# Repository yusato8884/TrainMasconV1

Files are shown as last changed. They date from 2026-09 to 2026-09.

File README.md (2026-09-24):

# TrainMasconV1

自作ゲーム「[Tozai Sim Pro](https://tozai-sim.base44.app/)」用の、USBキーボードとして動作する自作マスコン（主幹制御器）コントローラーです。
可変抵抗（2連ボリューム）のレバー位置を読み取り、ノッチ（P4〜N〜B7〜EB）に応じたキー入力をPCへ送ります。
現在のノッチは0.96インチOLEDに大きく表示されます。

- マイコン: AE-RP2040（MicroPython）
- 表示: SSD1306 OLED 128x64（I2C）
- 入力: 可変抵抗 1個（ADC）＋ ボタン 3個
- 接続: USB HID キーボード

ドキュメント: <https://y-trm1doc.base44.app/>

## ディレクトリ構成

```
Firmware/
  LICENSE                               ソフトウェアのライセンス（MIT）
  main.py                               本体ファームウェア（ノッチ→キー入力、OLED表示、USB HID）
  vrcalib.py                            可変抵抗の電圧測定ツール（ノッチ境界の電圧調整用）
Hardware/
  Enclosure/                            3Dプリント用ケース
    TRM1-Case-Top.stl                   ケース上部
    TRM1-Case-Bottom.stl                ケース下部
    TRM1-Case-Handle.stl                ハンドル
    TRM1-Case-Handle-Stopper.stl        ハンドルのストッパー
  PCB/                                  基板データ
    ProPrj_Mascon_2026-09-23.epro2      EasyEDA Pro の原本
    kicad_output/                       KiCad 8 変換版
      Mascon.kicad_pro                  KiCad プロジェクトファイル
      Mascon.kicad_sch                  回路図
      Mascon.kicad_pcb                  基板
      Mascon.kicad_sym                  シンボルライブラリ
      Mascon.kicad_footprints.pretty/   フットプリントライブラリ（.kicad_mod 8点）
      fp-lib-table                      フットプリントライブラリ設定
      sym-lib-table                     シンボルライブラリ設定
      CONVERSION_NOTES.md               変換時の注意事項
  LICENSE                               ハードウェアのライセンス（CERN-OHL-P v2）
README.md                               このファイル
```

## 配線

| 部品 | ピン |
|---|---|
| OLED SDA / SCL | GP20 / GP19（SoftI2C, アドレス 0x3C） |
| ボタン1 / 2 / 3 | GP23 / GP24 / GP25（GND側に接続） |
| 可変抵抗（中点） | GP26 (ADC0)、両端は 3V3 と GND |

## セットアップ

1. AE-RP2040 に MicroPython を書き込みます。
2. 必要なライブラリを導入します。
   ```
   mpremote mip install ssd1306
   mpremote mip install usb-device-keyboard
   ```
3. `Firmware/main.py` を `main.py` として本体に転送します。
4. USBで接続すると、キーボードとして認識されます。

## ノッチの調整

1. `Firmware/vrcalib.py` を実行し、レバーを各ノッチに合わせたときの電圧を読み取ります。
2. `main.py` の `LAYERS` の電圧しきい値（下限V, 上限V）を書き換えます。

既定のキー割り当ては次のとおりです（電圧の低い側から）。

| ノッチ | P4 | P3 | P2 | P1 | N | B1〜B6 | B7 | EB |
|---|---|---|---|---|---|---|---|---|
| キー | 1 | 2 | 3 | 4 | → | 5, 6, 7, 8, 9, 0 | - | Space |

ボタン1を押しながら起動すると安全モード（HID初期化とメインループを行わない）になり、ファイルを編集できます。

## ハードウェア

- `Hardware/PCB/ProPrj_Mascon_2026-09-23.epro2` が基板の原本です。
- `Hardware/PCB/kicad_output/` は KiCad 8 向けの変換結果です（開く場合は `Mascon.kicad_pro` を指定します）。KiCad での動作確認は未実施のため、開く際は [CONVERSION_NOTES.md](Hardware/PCB/kicad_output/CONVERSION_NOTES.md) を確認してください。
- ケースのSTL（`Hardware/Enclosure/` 内の `TRM1-Case-*.stl` 4点）についての注意:
  - サポート材は含まれていません。造形方向やプリンターに応じて、必要ならスライサー側で追加してください。
  - 薄肉部分やクリアランス（はめ合いの隙間）は十分に考慮されていません。
  - そのため、3Dプリントサービスに発注するか、自分で造形する場合は精度の非常に高いプリンター（光造形など）が必要です。一般的なFDMプリンターでは、そのままでは組み立てられない可能性があります。

## ライセンス

ライセンスは、対象ごとにそれぞれのフォルダ内の `LICENSE` に記載されています。

| 対象 | ライセンス | ファイル |
|---|---|---|
| ハードウェア（`Hardware/` 配下: 基板、回路図、ケース） | [CERN-OHL-P v2](Hardware/LICENSE) | `Hardware/LICENSE` |
| ソフトウェア（`Firmware/` 配下） | [MIT](Firmware/LICENSE) | `Firmware/LICENSE` |

SPDX: `CERN-OHL-P-2.0`（ハードウェア）/ `MIT`（ソフトウェア）

[SCANOSS](https://www.scanoss.com/) によるスキャンでは、全ファイルで既存OSSとの一致は検出されませんでした（2026-09-24時点）。

---

# TrainMasconV1

A custom mascon (master controller) controller for my original game "[Tozai Sim Pro](https://tozai-sim.base44.app/)", which operates as a USB keyboard.
It reads the lever position of a variable resistor (dual-gang potentiometer) and sends key inputs to the PC according to the notch (P4〜N〜B7〜EB).
The current notch is displayed prominently on a 0.96-inch OLED.

- Microcontroller: AE-RP2040 (MicroPython)
- Display: SSD1306 OLED 128x64 (I2C)
- Input: 1 variable resistor (ADC) + 3 buttons
- Connection: USB HID keyboard

Documentation: <https://y-trm1doc.base44.app/>

## Directory Structure

```
Firmware/
  LICENSE                               Software license (MIT)
  main.py                               Main firmware (notch→key input, OLED display, USB HID)
  vrcalib.py                            Variable resistor voltage measurement tool (for adjusting notch boundary voltages)
Hardware/
  Enclosure/                            3D-printable case
    TRM1-Case-Top.stl                   Case top
    TRM1-Case-Bottom.stl                Case bottom
    TRM1-Case-Handle.stl                Handle
    TRM1-Case-Handle-Stopper.stl        Handle stopper
  PCB/                                  PCB data
    ProPrj_Mascon_2026-09-23.epro2      EasyEDA Pro original
    kicad_output/                       KiCad 8 converted version
      Mascon.kicad_pro                  KiCad project file
      Mascon.kicad_sch                  Schematic
      Mascon.kicad_pcb                  PCB layout
      Mascon.kicad_sym                  Symbol library
      Mascon.kicad_footprints.pretty/   Footprint library (8 .kicad_mod files)
      fp-lib-table                      Footprint library table
      sym-lib-table                     Symbol library table
      CONVERSION_NOTES.md               Notes on the conversion
  LICENSE                               Hardware license (CERN-OHL-P v2)
README.md                               This file
```

## Wiring

| Component | Pin |
|---|---|
| OLED SDA / SCL | GP20 / GP19（SoftI2C, address 0x3C） |
| Button 1 / 2 / 3 | GP23 / GP24 / GP25（connected to GND） |
| Variable resistor (center tap) | GP26 (ADC0), both ends to 3V3 and GND |

## Setup

1. Flash MicroPython onto the AE-RP2040.
2. Install the required libraries.
   ```
   mpremote mip install ssd1306
   mpremote mip install usb-device-keyboard
   ```
3. Transfer `Firmware/main.py` to the device as `main.py`.
4. When connected via USB, it will be recognized as a keyboard.

## Notch Adjustment

1. Run `Firmware/vrcalib.py` and measure the voltage when the lever is set to each notch.
2. Rewrite the voltage thresholds (lower limit V, upper limit V) in `LAYERS` in `main.py`.

The default key assignments are as follows (from the lower-voltage side).

| Notch | P4 | P3 | P2 | P1 | N | B1〜B6 | B7 | EB |
|---|---|---|---|---|---|---|---|---|
| Key | 1 | 2 | 3 | 4 | → | 5, 6, 7, 8, 9, 0 | - | Space |

Starting while holding Button 1 enters safe mode (HID initialization and the main loop are not executed), allowing files to be edited.

## Hardware

- `Hardware/PCB/ProPrj_Mascon_2026-09-23.epro2` is the original PCB design file.
- `Hardware/PCB/kicad_output/` contains the conversion results for KiCad 8 (open `Mascon.kicad_pro` to load the project). Since operation in KiCad has not been verified, check [CONVERSION_NOTES.md](Hardware/PCB/kicad_output/CONVERSION_NOTES.md) when opening the files.
- Notes on the case STL files (the four `TRM1-Case-*.stl` files in `Hardware/Enclosure/`):
  - Support material is not included. Add it in the slicer as necessary depending on the print orientation and printer.
  - Thin sections and clearances (gaps for fitting) have not been sufficiently taken into consideration.
  - Therefore, if ordering from a 3D printing service, or printing it yourself, a very high-precision printer (such as a resin printer) is required. With a typical FDM printer, it may not be possible to assemble it as-is.

## License

The license for each part is provided in the `LICENSE` file inside the corresponding folder.

| Target | License | File |
|---|---|---|
| Hardware (PCB, schematics, and case under `Hardware/`) | [CERN-OHL-P v2](Hardware/LICENSE) | `Hardware/LICENSE` |
| Software (under `Firmware/`) | [MIT](Firmware/LICENSE) | `Firmware/LICENSE` |

SPDX: `CERN-OHL-P-2.0` (hardware) / `MIT` (software)

According to a scan by [SCANOSS](https://www.scanoss.com/), no matches with existing OSS were detected across all files (as of 2026-09-24).

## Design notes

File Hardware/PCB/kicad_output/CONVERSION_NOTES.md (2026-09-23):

# Mascon: EasyEDA Pro から KiCad 8 への変換メモ

- 変換元: `ProPrj_Mascon_2026-09-23.epro2`（EasyEDA Pro / 嘉立創EDA専業版 v3.2）
- 変換スクリプト: `../convert_epro2.py`（再エクスポートしたときは再実行してください）
- 検証スクリプト: `../verify_kicad_output.py`（KiCad なしで構文、個数、ネットを照合します）
- 変換先の形式: KiCad 8.0（pcb/mod は `20240108`、sch/sym は `20231120`）

```
python3 convert_epro2.py ProPrj_Mascon_2026-09-23.epro2 kicad_output
python3 verify_kicad_output.py kicad_output Mascon
```

> **注意:** この環境には KiCad がインストールされていません。そのため、KiCad の GUI で実際に開いて確認する作業はまだ行っていません。
> 検証はテキスト解析と独立したロジックによるネット照合だけです。最初に KiCad で開いたときに、下の「手動で確認・修正すべき点」を実施してください。

## 出力ファイル

| ファイル | 内容 |
|---|---|
| `Mascon.kicad_pro` | 最小構成のプロジェクトファイル（Default ネットクラスのみ） |
| `sym-lib-table` / `fp-lib-table` | プロジェクトローカルのライブラリ設定（ニックネーム `Mascon`, `${KIPRJMOD}` 相対） |
| `Mascon.kicad_sym` | シンボルライブラリ（10 個）。回路図で使用中の 6 個に加え、ライブラリにあるだけの未使用部品 4 個（PTD904、Res_0603、PZ254V-11-04P、M3 ネジ）を含みます |
| `Mascon.kicad_footprints.pretty/` | フットプリントライブラリ（8 個、下表） |
| `Mascon.kicad_sch` | 回路図 1 枚（A4）。シンボル 17 個（部品 7 個＋電源シンボル 10 個）、ワイヤー 25 本 |
| `Mascon.kicad_pcb` | 4 層基板（80 × 45 mm）。フットプリント 7 個、配線 62 本、円弧配線 2 本、ゾーン 2 つ |

### フットプリント

| 名前 | 元のパッド数 | KiCad 側のパッド数 | 使用箇所 |
|---|---|---|---|
| 基板取付用2連ボリューム | 6 | 6 | VR1 |
| 0_96in_OLED | 4 | 4 | H3 |
| SW-TH_4P-L12.0-W12.0-P5.00-LS12.5 | 4 | 4 | U1–U3 (FSM101) |
| HDR-TH_17P-P2.54-V-M | 17 | 17 | H1, H2 |
| HDR-TH_4P-P2.54-V-M | 4 | 4 | ライブラリのみ |
| RES-ADJ-TH_PTD904-2015K-A203 | 12 | 12 | ライブラリのみ |
| R0603 | 2 | 2 | ライブラリのみ |
| SMD_BD5.5-D3.9 | 4 | 5 (*) | ライブラリのみ |

(*) 多層 FILL（ネジ穴部分）を NPTH（φ4.3 mm）として 1 つ追加しています。

次の 2 つは変換していません。どちらも DEVICE や基板から参照されていない重複データです。
- `29170b2ba65da5d1`: 基板取付用2連ボリュームの旧版
- `165ee28e8539ce30`: 0_96in_LCD（OLED と同じ出典のコピー）

## 問題なく変換できたもの

- **部品配置**: 基板上の座標、回転、リファレンス（H1, H2, H3, U1–U3, VR1）はすべて元データどおりです。
- **パッド**: 形状は rect / circle / oval / custom（ポリゴン）に対応しています。穴径、スルーホールか SMD か、パッド角度も反映しています。
- **ネット**: `PAD_NET` をそのまま使っています（`VCC`, `GND`, `$1N9`, `$1N14`, `$1N15`, `$1N16`, `$1N21`, `$1N22`）。
- **配線**: 表面と裏面の配線 62 本、円弧配線 2 本の層とネットを保持しています。回避用の円弧の向きもパッドとの位置関係から確認済みです。
- **基板外形**: 矩形 80 × 45 mm と取付穴 4 つ（φ4.4 mm の Edge.Cuts 円）です。
- **層構成**: 表面、In1.Cu（GND プレーン）、In2.Cu（VCC プレーン）、裏面の 4 層です。
- **回路図**: 部品の配置と回転、ワイヤー、GND/VCC の電源シンボル（KiCad の power シンボルとして作成）を変換しています。
- **シンボルのフィールド**: フットプリント（`Mascon:...`）、データシート、MPN、LCSC 番号をシンボルのフィールドに入れています。
- **回路図と基板の対応付け**: 各フットプリントの `(path)` を回路図シンボルの UUID に合わせてあります。そのため「回路図から PCB を更新」で既存の部品として扱われます。
- **シルク印刷**: テキスト 6 つとロゴ（電車アイコン、表裏）を変換しています。ロゴは穴付きポリゴンを切れ込み（keyhole）でつないだ塗りつぶし図形です。

## 近似したもの、または省略したもの

1. **内層プレーン（GND/VCC）**
   - 基板外形いっぱいの KiCad ゾーンとして作り直しています。塗りつぶし結果は保存していないので、開いたら `B`（全ゾーンを再塗りつぶし）を押してください。
   - クリアランス 0.3 mm とサーマル 0.5 mm は仮の値です。EasyEDA 側の値ではありません。
2. **シルクのテキスト**
   - 元は TrueType（Google Sans）です。KiCad では標準のストロークフォントを使い、元の fontSize × 0.7 の大きさにしています。
   - 位置や幅は目安です。裏面のテキストは `mirror` を付けていますが、左右どちら向きに伸びるかは未確認です。
3. **3D モデル**: 変換していません（EasyEDA のモデル ID しかないため）。
4. **デザインルール**: RULE / RULE_SELECTOR は移していません。KiCad の既定値（クリアランス 0.2 mm、配線幅 0.254 mm など）になっています。
   - EasyEDA ではソルダーマスクの拡張が 2 mil でした。KiCad 側は 0 です。
5. **FILL（層 50/51）**: ピンのはんだ付け範囲を表す補助図形で、パッドと重複するため省略しました。
6. **層 48/49 の図形**: 部品外形と 1 ピン目の印です。F.Fab に置いています。
7. **SMD_BD5.5-D3.9 の多層 FILL**: NPTH 穴として近似しています（未配置の部品です）。
8. **回路図の図枠（Drawing-Symbol_A4）**: シンボルとしては配置していません。KiCad 標準の A4 図枠とタイトル欄（タイトル「Mascon」、日付、版 V1.0）に置き換えています。
9. **孤立したワイヤー線分 7 本**: WIRE レコードが存在しない LINE 群です。EasyEDA 上で削除されたワイヤーの残骸と判断して捨てました。
   - これらはどのピンにもつながっていません。捨てた後のネットは基板の PAD_NET と完全に一致しています。
10. **削除済みオブジェクト**: 本体が空のレコード（PAD_NET 110 件、LINE 41 件など）は削除済みとして無視しています。

## 手動で確認・修正すべき点

1. **ゾーンを再塗りつぶしして DRC を実行する**: PCB を開いて `B` を押し、DRC を実行してください。
   - GND/VCC のスルーホールは内層プレーンだけでつながっています。塗りつぶすまでは「未配線」と表示されます。
2. **ERC の警告を確認する**。次の警告が出る見込みです。
   - 未接続ピン: H1 の全ピン（RP2040 モジュールを機械的に固定するだけ）、H2 の未使用ピン、VR1 の 4–6 ピン（2 連の片側）、U1–U3 の 1 と 4 ピン。
     元データに未接続フラグ（No Connect）がないためです。意図どおりなら No Connect フラグを置いてください。
   - GND/VCC が「電源出力に駆動されていない」: 必要なら `PWR_FLAG` を追加してください。
   - FSM101 と 17 ピンヘッダーのピン種別は元データで Undefined でした。そのため KiCad では `unspecified` になっています。
3. **ネット名**: 自動ネットは EasyEDA の名前（`$1N9` など）のまま基板に書いています。回路図にはラベルがありません。
   - 「回路図から PCB を更新」を実行すると、KiCad が `Net-(H2-Pad6)` 形式に名前を変えることがあります。つながり自体は変わりません。
4. **フットプリントを目視で確認する**。
   - VR1（基板取付用2連ボリューム）: 1 ピン（角パッド）の位置と、シルク枠が基板の左端にはみ出していないかを見てください（元データでも枠は x=0 付近）。
   - H3（OLED）: 27.3 mm 角のシルク枠とピン順（1 GND, 2 VCC, 3, 4）。
5. **裏面のシルク**: 「Train Mascon」「V1.0 ©2026 Yu Sato」と電車ロゴの位置と向きを 3D ビューアで確認してください。
6. **基板の厚さ**: EasyEDA の積層の合計は約 1.59 mm です。KiCad 側は 1.6 mm にしてあり、詳しい積層は設定していません。発注前に基板設定で確認してください。

## 解析した EasyEDA Pro 形式の仕様と確信度

| 項目 | 内容 | 確信度 |
|---|---|---|
| 行の形式 | `{header}||{body}|`。本体が空なら削除済み、DOCHEAD でサブドキュメントが切り替わる | 高 |
| 部品とライブラリの対応 | 部品の子 ATTR の `Symbol` / `Device` / `Footprint` で対応付く。部品側の Footprint 属性が DEVICE より優先（H3 の OLED で確認）。`partId` は同じシンボル内の PART（ユニット）を選ぶだけ | 高 |
| 回路図の座標 | 1 単位 = 10 mil、Y 軸は下向き、回転は見た目で反時計回り。PIN の (x,y) が接続点。ワイヤー端点との一致数で 2 通りの仮説を比べて確定 | 高 |
| PCB とフットプリントの座標 | mil 単位、Y 軸は上向き、角度は反時計回り。配線端点とパッド位置、PAD_NET のネットが全部一致することで確認 | 高 |
| 円弧 `["ARC", 角度, x, y]` | 角度は反時計回りが正（Y 上向き）。パッドを避ける向きになることで確認 | 中〜高 |
| 矩形 `["R", x, y, w, h, r]` | (x, y) が左上で、y−h まで伸びる（Y 上向き） | 高 |
| ポリゴンパッドの座標 | フットプリント上の絶対座標 | 高 |
| LAYER_FILL | プレーンの計算済み塗りつぶし（円弧の角度は 0.1° 単位らしい）。ネット名と層だけを使用 | 中 |
| IMAGE | 元図形は Y 上向き。バウンディングボックスを width/height に合わせて拡大縮小 | 中 |
| パッドの角度と width/height | width は回転前の X 方向の寸法 | 中（この基板では正方形か円のパッドばかりで影響なし） |

## 検証結果（verify_kicad_output.py）

- **構文**: 生成したファイル 13 個（sch, pcb, sym, lib-table 2 つ, kicad_mod 8 つ）が、厳密な S 式パーサで解析できることを確認しました。
- **回路図**: 17 シンボル、25 ワイヤー。宙に浮いたワイヤー端は 0 です。
  - KiCad の座標の扱い（ライブラリは Y 上向き、回転は反時計回り）に従ってピン位置を計算し直しました。複数ピンのネットは 8 個でした。
- **基板**: フットプリント 7、パッド 56（元データとすべての部品で一致）、ネット 8、配線 62、円弧 2、ゾーン 2、Edge.Cuts 5。
- **回路図と基板の照合**: 複数ピンのネット 8 個が完全に一致しました（PASS）。
- **配線の照合**: 配線で結ぶ 6 ネットは、KiCad の座標の扱いで計算したパッド位置に配線がつながり、ネットごとに 1 つにまとまることを確認しました。
  - 別ネットのパッドに乗っている配線端は 0 です。GND/VCC は内層ゾーンでつながります。

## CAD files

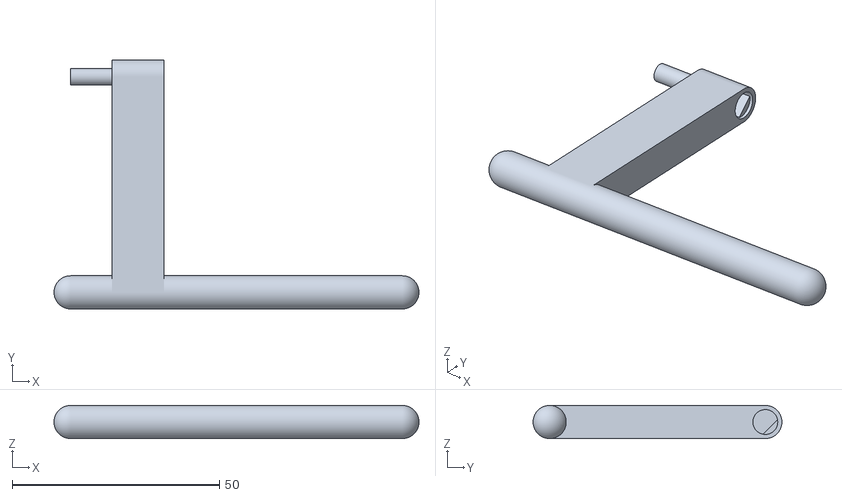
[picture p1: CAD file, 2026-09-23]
Hardware/Enclosure/TRM1-Case-Handle.stl
88.0 x 60.0 x 8.00

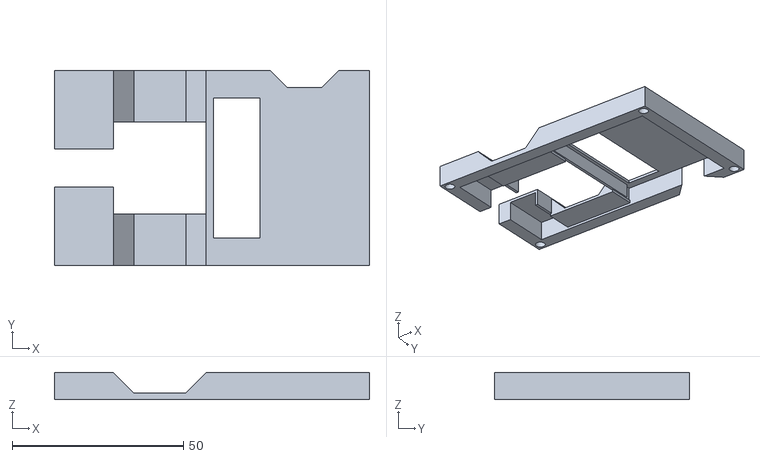
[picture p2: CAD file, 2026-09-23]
Hardware/Enclosure/TRM1-Case-Top.stl
92.0 x 57.0 x 8.00

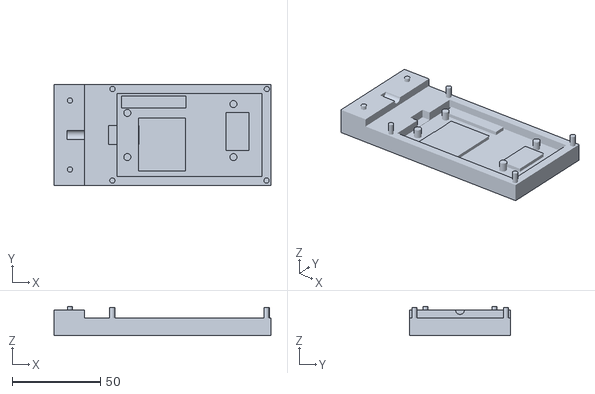
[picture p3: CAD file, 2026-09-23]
Hardware/Enclosure/TRM1-Case-Bottom.stl
122.8 x 57.0 x 16.5

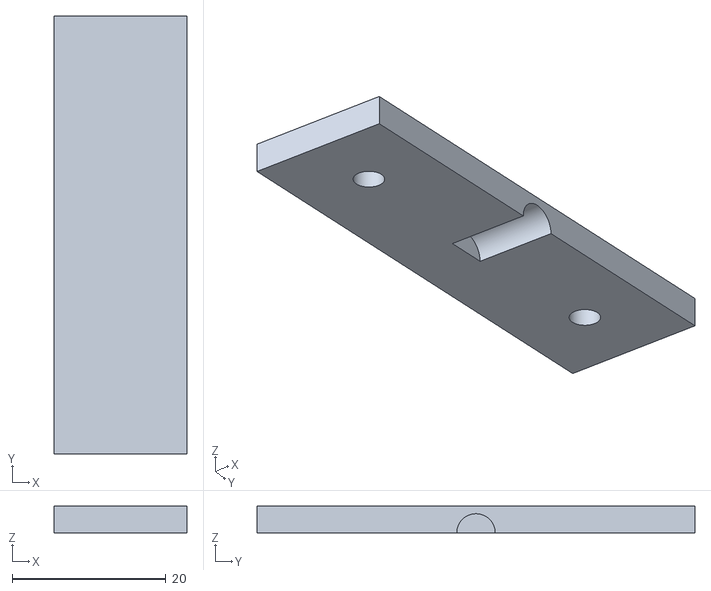
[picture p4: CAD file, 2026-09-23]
Hardware/Enclosure/TRM1-Case-Handle-Stopper.stl
17.2 x 57.0 x 3.50

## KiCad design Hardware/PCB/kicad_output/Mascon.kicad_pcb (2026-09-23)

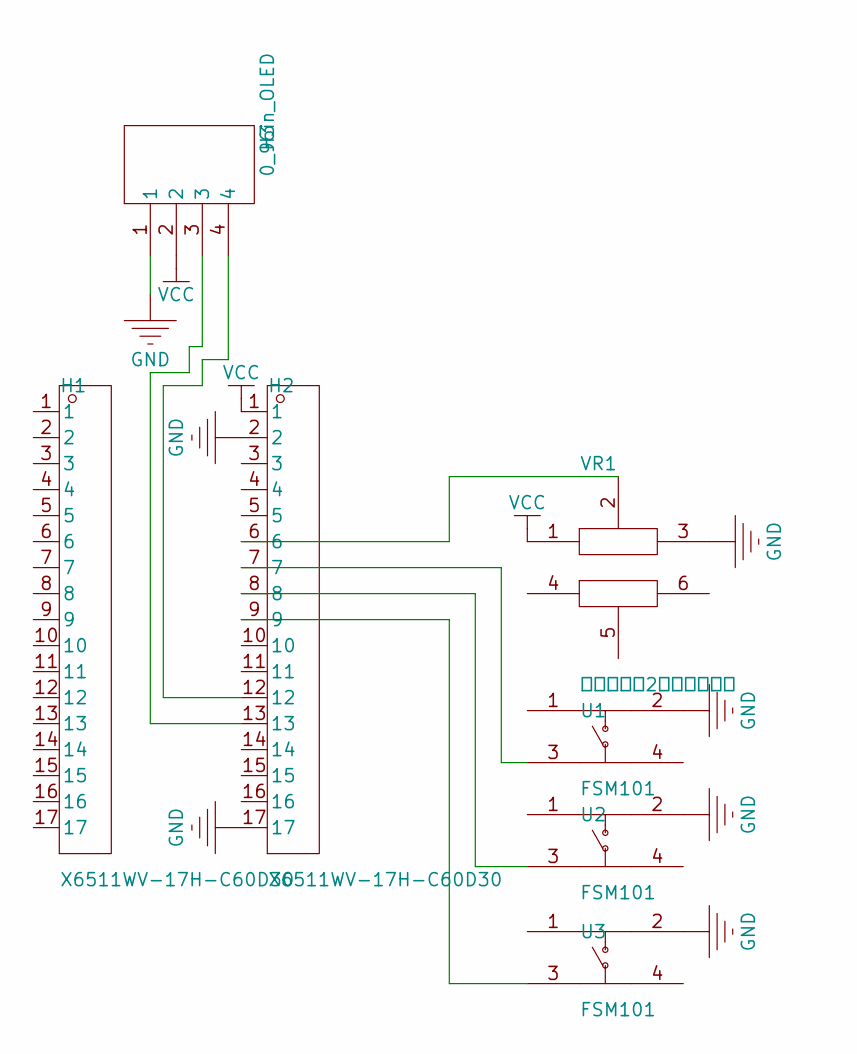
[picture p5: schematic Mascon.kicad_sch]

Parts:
H1, H2: X6511WV-17H-C60D30; HDR-TH_17P-P2.54-V-M; MPN X6511WV-17H-C60D30; LCSC C725949
H3: 0_96in_OLED
U1, U2, U3: FSM101; SW-TH_4P-L12.0-W12.0-P5.00-LS12.5; MPN FSM101; LCSC C5340381
VR1: 基板取付用2連ボリューム

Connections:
$1N9: H2.6, VR1.2
$1N14: H2.7, U1.3
$1N15: H2.8, U2.3
$1N16: H2.9, U3.3
$1N21: H2.12, H3.4
$1N22: H2.13, H3.3
GND: H2.2, H2.17, H3.1, U1.2, U2.2, U3.2, VR1.3
VCC: H2.1, H3.2, VR1.1

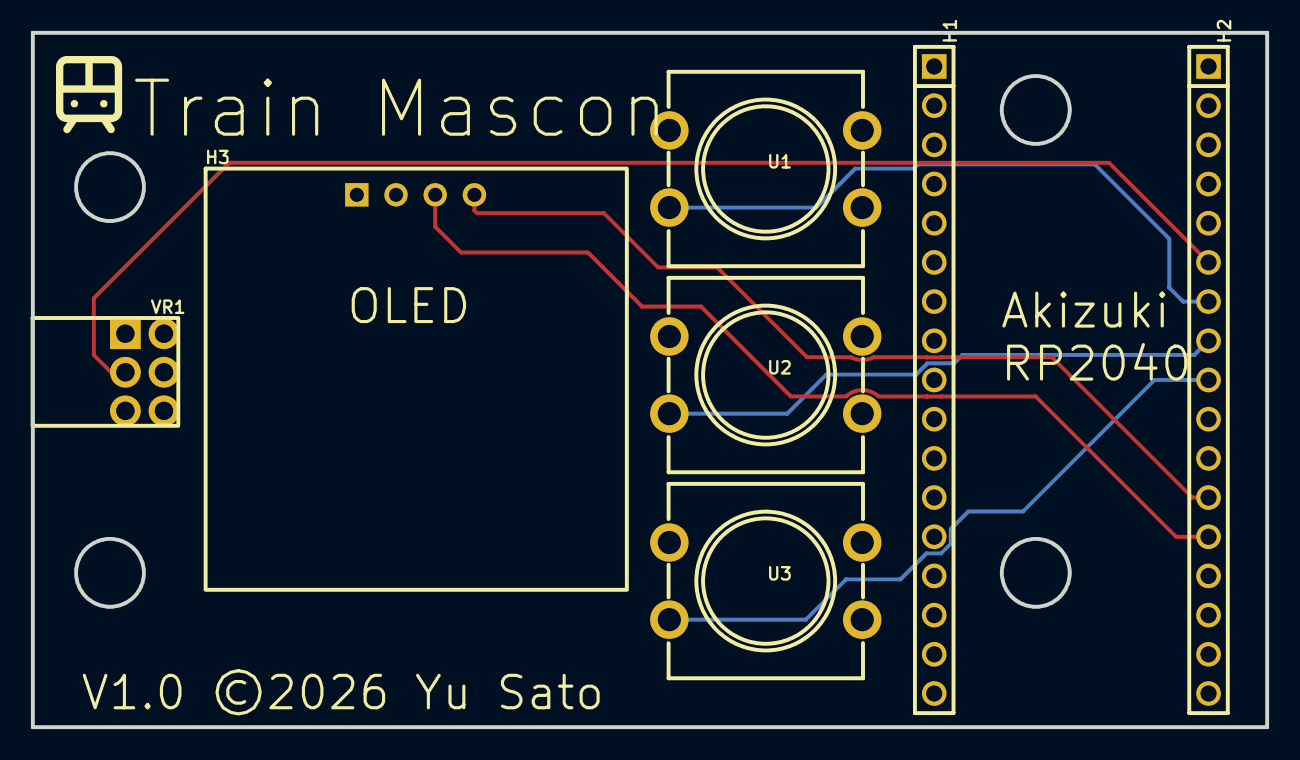
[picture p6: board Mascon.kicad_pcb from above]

Board: 4 copper layers, 80.0 x 45.0 mm, 7 parts (0 on the bottom side), 8 nets.

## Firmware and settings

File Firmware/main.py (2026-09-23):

# -*- coding: utf-8 -*-
"""
AE-RP2040 / MicroPython
可変抵抗とボタンで文字を入力する簡易キーボード

仕様
  ・可変抵抗：角度(電圧)が別の範囲に変わった瞬間、その範囲のキーを1回入力
  ・ボタン  ：押した瞬間、そのボタンに割り当てたキーを1回入力（各ボタン独立）
  ・ボタンは長押しでリピート入力（可変抵抗もPOT_REPEAT=Trueで同様に）
  ・OLED   ：可変抵抗で今選んでいる文字を、太字・中央揃えで表示

配線
  OLED (SSD1306, I2C)  SDA=GP20 / SCL=GP19  ※SoftI2C
  ボタン1              GP23  --- GND
  ボタン2              GP24  --- GND
  ボタン3              GP25  --- GND
  可変抵抗             ADC0 (GP26) の中点、両端は 3V3 と GND

必要ライブラリ: ssd1306.py を AE-RP2040 に転送しておいてください
  (mpremote mip install ssd1306  など)
"""

from machine import Pin, SoftI2C, ADC
import time
import framebuf
import gc

import ssd1306

# ============================================================
# 設定
# ============================================================

PIN_SDA = 20
PIN_SCL = 19
PIN_BUTTONS = (23, 24, 25)   # B1, B2, B3
PIN_POT = 26                 # ADC0

OLED_W, OLED_H = 128, 64
OLED_ADDR = 0x3C

VREF = 3.3                   # ADCの基準電圧[V]


# --- OLED表示の設定 ------------------------------------------
# 可変抵抗で今選んでいるキーの「表示用文字列」を、
# 大きな太字・中央揃えでOLEDに表示します。
DISPLAY_BOLD = True   # True=太字, False=普通の太さ
TEXT_SCALE = 6        # 文字の拡大倍率。標準8pxの何倍にするか（1文字なら6〜7が大きめ）

FONT_W = 8            # 標準フォントの1文字の幅[px]
FONT_H = 8            # 標準フォントの1文字の高さ[px]


# --- キー配列（マスコン）-------------------------------------
# (下限電圧, 上限電圧, キー, 表示ラベル) のタプルを並べます。
#   下限 <= 電圧 < 上限  のときそのマスコン位置が選ばれます。
#   3番目「キー」  … その位置のとき送るキー（HID）。特殊キーは "RIGHT" 等の名前。
#   4番目「ラベル」… OLEDに大きく表示する文字（P4 / N / B3 / EB など）。
# 電圧は後で調整する前提の“とりあえず等分”です。数値だけ書き換えれば調整できます。
# 並びは電圧の小さい順。P4が電圧の低い方（一番上のノッチ）です。

LAYERS = {
    "mascon": [
        # (下限V, 上限V, キー,     ラベル)  ※0.9〜3.3Vを均等13分割
        (0.900, 1.085, "1",    "P4"),   # ← 電圧が低い方
        (1.085, 1.269, "2",    "P3"),
        (1.269, 1.454, "3",    "P2"),
        (1.454, 1.638, "4",    "P1"),
        (1.638, 1.823, "RIGHT", "N"),    # N = 右矢印キー
        (1.823, 2.008, "5",    "B1"),
        (2.008, 2.192, "6",    "B2"),
        (2.192, 2.377, "7",    "B3"),
        (2.377, 2.562, "8",    "B4"),
        (2.562, 2.746, "9",    "B5"),
        (2.746, 2.931, "0",    "B6"),
        (2.931, 3.115, "-",    "B7"),
        (3.115, 3.300, " ",    "EB"),   # EB = Space
    ],
}
LAYER_ORDER = ["mascon"]


# --- ボタンに割り当てるキー -----------------------------------
# ボタンを押した「瞬間」からそのキーを押し続け、離した瞬間に解除します。
# 同時押しに特別な意味はありません（各ボタンは独立）。
#   ボタン1(GP23) = Enter
#   ボタン2(GP24) = H （Shiftなし。大文字にしたい場合は "H" にする）
#   ボタン3(GP25) = B （Shiftなし。大文字にしたい場合は "B" にする）
BUTTON_KEYS = ["\n", "h", "b"]


# --- タイミング / 精度 ----------------------------------------
DEBOUNCE_MS = 20      # チャタリング除去[ms]
TAP_MS = 12           # タップ入力の押下→解放の間隔[ms]（短すぎると取りこぼす）
HID_TIMEOUT_MS = 30   # HID送信の最大待ち時間[ms]。大きいと固まりやすく、0で待たない
POT_SAMPLES = 8       # 可変抵抗の平均化サンプル数
POT_HYST_V = 0.03     # ヒステリシス[V]。境界付近のブレが気になるなら増やす

# 万一フリーズしても自動リセットで復帰させる安全装置（ウォッチドッグ）
# 注意: 一度オンにすると停止できず、編集中もリセットがかかって保存しづらくなる。
#       まずは False のまま使い、動作が安定してから必要なら True にする。
#       True にしても、ボタン1を押しながら起動すれば安全モードで編集できる。
USE_WATCHDOG = False  # True=有効。ハングしても数秒で自動リセットして復帰
WATCHDOG_MS = 4000    # この時間 反応が無いと自動リセット[ms]（RP2040は最大約8300）

# 長押しのリピート（同じ文字が連続入力される）はPC側の設定で行われます。
# このプログラムは「押している間キーを押し続ける」ことだけを担当します。

# 可変抵抗を同じ範囲に留めているときの動作
#   False = 範囲に入った瞬間に1回だけ入力（既定・タップ）
#   True  = 留めている間はそのキーを押し続ける（＝長押し。リピートはPC側）
POT_REPEAT = False

MAX_BUFFER = 200      # 入力バッファの最大文字数


# --- 起動画面（スプラッシュ）の設定 ---------------------------
BOOT_TEXT = ["Train", "Mascon"]   # 起動画面 右側に出す文字（1要素=1行）
BOOT_HOLD_S = 2          # 起動画面を表示する秒数
ICON_SIZE = 54           # アイコンの一辺[px]
ICON_PAD = 10            # 左の余白 & 画像とテキストの間隔[px]
ICON_FILE = "icon.txt"   # ICON_TEXTが空のとき読むファイル（0/1のテキスト）
# ※アイコンの絵そのもの(0/1データ = ICON_TEXT)は、下の「起動画面」セクションにあります


# --- USB（HID）の設定 ---------------------------------------
USE_HID = True    # True: USBキーボードとして入力を送る / False: printだけ
# 下のプロパティは None なら MicroPython の既定値。値を入れればそれが反映されます。
DEVICE_NAME   = "TrainMasconV1"   # PCに表示されるデバイス名（product string）
MANUFACTURER  = "Yu Sato"         # 製造者名（例: "Yu"）。不要なら None
USB_VID       = None              # ベンダーID（例: 0xF055）。None=既定
USB_PID       = None              # プロダクトID（例: 0x9802）。None=既定
USB_SERIAL    = None              # シリアル番号文字列。None=既定
USB_MAX_POWER = 100               # 最大消費電流[mA]（例: 100）。None=既定


# ============================================================
# ハードウェア初期化
# ============================================================

i2c = SoftI2C(sda=Pin(PIN_SDA), scl=Pin(PIN_SCL), freq=100000)
oled = ssd1306.SSD1306_I2C(OLED_W, OLED_H, i2c, addr=OLED_ADDR)

buttons = [Pin(p, Pin.IN, Pin.PULL_UP) for p in PIN_BUTTONS]
pot = ADC(PIN_POT)

# 起動時の脱出口（安全モード）:
#   ボタン1を押しながら電源を入れる/リセットすると、HID初期化・メインループ・
#   ウォッチドッグを一切始めずにREPLへ落ちる。
#   自動実行やウォッチドッグでソースを書き換えられないときに使う。
SAFE_MODE = (buttons[0].value() == 0)   # ボタン1が押されていれば安全モード


_oled_fail = 0

def oled_show():
    """OLEDへの書き込み。I2Cが一時的に失敗(ENODEV等)しても落ちないようにする。
    連続で失敗したら、表示を初期化し直して復帰を試みる。"""
    global _oled_fail
    try:
        oled.show()
        _oled_fail = 0
    except OSError:
        _oled_fail += 1
        if _oled_fail >= 5:
            _oled_fail = 0
            try:
                oled.init_display()   # 一度リセットして立て直す
            except OSError:
                pass                  # それでも駄目なら次のフレームで再挑戦


def read_voltage():
    """可変抵抗の電圧[V]を返す"""
    total = 0
    for _ in range(POT_SAMPLES):
        total += pot.read_u16()
    return (total / POT_SAMPLES) / 65535.0 * VREF


# ============================================================
# OLEDへの文字表示（拡大・太字・中央揃え）
# ============================================================

def draw_big_center(s, scale, bold=True):
    """
    文字列 s を scale 倍に拡大し、画面の中央（縦横とも）に描く。
    標準フォント(8x8)の1ドットを scale×scale の正方形に拡大する。
    （1bitのOLEDなので“にじみ”は作れないが、大きく均一なドットにすることで
      ファミコンのタイル文字のようにくっきり見せる）
    """
    oled.fill(0)

    if not s:
        oled_show()
        return

    w = len(s) * FONT_W        # 元の文字列の幅[px]
    h = FONT_H                 # 元の高さ[px]

    # 画面からはみ出さないように、必要なら倍率を自動で下げる
    scale = min(scale, OLED_W // w, OLED_H // h)
    if scale < 1:
        scale = 1

    # 元サイズの文字を一時バッファ(モノクロ)に描く
    row_bytes = (w + 7) // 8   # MONO_HLSBは1行あたり ceil(w/8) バイト
    buf = bytearray(row_bytes * h)
    fb = framebuf.FrameBuffer(buf, w, h, framebuf.MONO_HLSB)
    fb.fill(0)
    fb.text(s, 0, 0, 1)

    # 拡大後のサイズと、中央に置くための左上座標
    out_w = w * scale
    out_h = h * scale
    x0 = (OLED_W - out_w) // 2
    y0 = (OLED_H - out_h) // 2

    # 太字は「上下左右に1pxずつ均等に膨らませる」ことで太くする（横だけ太る不均一を防ぐ）
    grow = 1 if bold else 0
    block = scale + 2 * grow

    # 点いているドットを scale 角の正方形として描く
    for y in range(h):
        for x in range(w):
            if fb.pixel(x, y):
                oled.fill_rect(x0 + x * scale - grow,
                               y0 + y * scale - grow,
                               block, block, 1)

    oled_show()


# ============================================================
# 大きめフォント（DejaVuSans Bold を1bit化して埋め込み）
#   荒い8x8の拡大をやめ、これでマスコンのラベルをきれいに描く。
#   対応文字は 0-9 / A-Z / "-"。対応外が混ざる場合だけ従来の拡大表示に切替。
# ============================================================
import binascii

GLYPH_H = 48
_GLYPHS = {
    '0': (28, 0),
    '1': (24, 168),
    '2': (26, 312),
    '3': (26, 468),
    '4': (28, 624),
    '5': (26, 792),
    '6': (28, 948),
    '7': (26, 1116),
    '8': (28, 1272),
    '9': (28, 1440),
    'A': (36, 1608),
    'B': (28, 1824),
    'C': (29, 1992),
    'D': (32, 2166),
    'E': (25, 2358),
    'F': (24, 2508),
    'G': (33, 2652),
    'H': (31, 2850),
    'I': (9, 3036),
    'J': (15, 3090),
    'K': (33, 3180),
    'L': (25, 3378),
    'M': (38, 3528),
    'N': (31, 3756),
    'O': (35, 3942),
    'P': (28, 4152),
    'Q': (35, 4320),
    'R': (31, 4530),
    'S': (27, 4716),
    'T': (32, 4878),
    'U': (30, 5070),
    'V': (36, 5250),
    'W': (49, 5466),
    'X': (35, 5760),
    'Y': (35, 5970),
    'Z': (30, 6180),
    '-': (15, 6360),
}
_FONT_B64 = "AAAAgMDg8Pj4+Pz8/Pz8/Pz8+Pj48ODAgAAAAID4/v///////w8DAQAAAAABAw/////////++ID///////////8AAAAAAAAAAAAA////////////AA8/////////+ODAgICAgMDg+P///////z8PAAAAAAABAwcPDw8fHx8fHx8fHw8PDwcDAQAAAAAAAAAAAAAAAAAAAAAAAAAAAAAAAAAAAAAAAAAA4ODw8PDw+Pj4+Pj4+Pj4+AAAAAAAAAAABwcDAwMDAQH//////////wAAAAAAAAAAAAAAAAAAAAD//////////wAAAAAAAAAAgICAgICAgID//////////4CAgICAgICAHx8fHx8fHx8fHx8fHx8fHx8fHx8fHx8fAAAAAAAAAAAAAAAAAAAAAAAAAAAAAAAAAPD4+Pj4+Pz8/Pz8/Pz8/Pz4+PDw4MCAAAAABwMDAQEBAAAAAAAAAQMH//////////98AAAAAAAAAAAAgIDA4PD4/v///38/Hw8HAQAAAMDg8Pj8/v////+/n4+Hg4GAgICAgICAgAAAHx8fHx8fHx8fHx8fHx8fHx8fHx8fHx8fAAAAAAAAAAAAAAAAAAAAAAAAAAAAAAAAAAAAAADw+Pj4+Pz8/Pz8/Pz8/Pz4+Pjw8ODAAAAAAAMBAQEAAAAAAAAAgYHD/////////38MAAAAAAAAAD8/Pz8/Pz9/f///////+fnw4IAA4MDAwMCAgICAgICAgMDA4PH/////////fwAPDw8fHx8fHx8fHx8fHx8fDw8PBwcDAwAAAAAAAAAAAAAAAAAAAAAAAAAAAAAAAAAAAAAAAAAAAAAAAAAAAADA4Pj4+Pj4+Pj4+PgAAAAAAAAAAAAAgMDw+P7//z8fB///////////AAAAAACA4PD8/v9/Pw8HAQAAAAD//////////wAAAAAAf39/f39/fn5+fn5+fn5+//////////9+fn5+fgAAAAAAAAAAAAAAAAAAAB8fHx8fHx8fAAAAAAAAAAAAAAAAAAAAAAAAAAAAAAAAAAAAAAAAAAAAAAD4+Pj4+Pj4+Pj4+Pj4+Pj4+Pj4+PgAAAAAAP/////////BwcHBwcHBwYGBgQEBAQAAAAAAPx8fHw8PDw8PDw8PHz9////////+/PCAAPDg4MDAwICAgICAgIDA4PD/////////fw8ABw8PDw8fHx8fHx8fHx8fDw8PDwcDAwAAAAAAAAAAAAAAAAAAAAAAAAAAAAAAAAAAAAAAAAAAAIDA4ODw+Pj4/Pz8/Pz8/Pz8+Pj48AAAAADA+P7//////z+Pg4HBwMDAwMDAgIEBAQMAAAAA////////////fx8PDw8PDx8////////+/PAAAAMff/////////DAgICAgIDA4P////////8/AAAAAAABAwcHDw8PHx8fHx8fHx8PDwcHAwEAAAAAAAAAAAAAAAAAAAAAAAAAAAAAAAAAAAAAAAAA+Pj4+Pj4+Pj4+Pj4+Pj4+Pj4+Pj4+Pj4+AABAQEBAQEBAQEBAQEBgeH5////////Pw8DAAAAAAAAAAAAAADA8P7//////38fBwAAAAAAAAAAAAAAgOD8////////Pw8BAAAAAAAAAAAAAAAAEB4fHx8fHx8fAwAAAAAAAAAAAAAAAAAAAAAAAAAAAAAAAAAAAAAAAAAAAAAAAAAAAACA4PDw+Pj4/Pz8/Pz8/Pz8/Pj4+PDw4IAAAAAAP//////////BwYCAgIDBwf///////38/AAAAgODw+Pn9//9/Pz8fHx8fHz/////9+fjw4IAAAH//////////4MCAgICAgIDA8P////////9/AAAAAQMHBw8PDx8fHx8fHx8fHx8PDw8HBwMBAAAAAAAAAAAAAAAAAAAAAAAAAAAAAAAAAAAAAAAAAACAwODw8Pj4/Pz8/Pz8/Pz4+Pjw4OCAAAAAAPD+/////////wMBAAAAAAABB//////////8wAAABx8/f3/////+/Pj4+Pj4/H9///////////8AAAAA4MDAwICBgYGBgYHBwOD4/v////9/Pw8BAAAAAAcPDw8fHx8fHx8fHx8PDw8HAwMBAAAAAAAAAAAAAAAAAAAAAAAAAAAAAAAAAAAAAAAAAAAAAAAAAAAAAAAAAADA+Pj4+Pj4+Pj4+PjwgAAAAAAAAAAAAAAAAAAAAAAAAADA8P7//////38PH/////////zggAAAAAAAAAAAAAAAAACA8P7///////8fAwAAAAAHP/////////zgAAAAAAAAAACA8P7///////9/f35+fn5+fn5+fn9/f/////////zgAAAAEB4fHx8fHx8fBwEAAAAAAAAAAAAAAAAAAAMPHx8fHx8fHxgAAAAAAAAAAAAAAAAAAAAAAAAAAAAAAAAAAAAAAAAAAAAAAAAA+Pj4+Pj4+Pj4+Pj4+Pj4+Pj4+PDw8ODgwAAAAP///////////wEBAQEBAQGDx///////////AAD///////////8/Pz8/Pz8/P3////////vx4MAA////////////gICAgICAgIDA4P//////////Px8fHx8fHx8fHx8fHx8fHx8fHx8fDw8PBwcDAAAAAAAAAAAAAAAAAAAAAAAAAAAAAAAAAAAAAAAAAAAAAIDAwODw8Pj4+Pz8/Pz8/Pz8/Pz4+Pj48PAA8Pz+////////Hw8DAwEBAAAAAAAAAAEBAQMDB3///////////4EAAAAAAAAAAAAAAAAAAAAAAAAAAAcfP/////////z44ODAwICAgICAgIDAwMDg4PAAAAAAAAEBAwcHDw8PHx8fHx8fHx8fHw8PDw8HBwAAAAAAAAAAAAAAAAAAAAAAAAAAAAAAAAAAAAAA+Pj4+Pj4+Pj4+Pj4+Pj4+Pj48PDw8ODgwMCAAAAAAAD///////////8BAQEBAQEBAwMHBw8//////////vjgAP///////////wAAAAAAAAAAAAAAAACB//////////9/////////////gICAgICAgMDA4ODw/P///////38fBwAfHx8fHx8fHx8fHx8fHx8fHx8PDw8PBwcDAwEAAAAAAAAAAAAAAAAAAAAAAAAAAAAAAAAAAAAAAAAAAAAAAAAA+Pj4+Pj4+Pj4+Pj4+Pj4+Pj4+Pj4+Pj4AP///////////wEBAQEBAQEBAQEBAQEBAQD///////////8/Pz8/Pz8/Pz8/Pz8/PwAA////////////gICAgICAgICAgICAgICAAB8fHx8fHx8fHx8fHx8fHx8fHx8fHx8fHwAAAAAAAAAAAAAAAAAAAAAAAAAAAAAAAAAA+Pj4+Pj4+Pj4+Pj4+Pj4+Pj4+Pj4+Pj4////////////AQEBAQEBAQEBAQEBAQEB////////////Pz8/Pz8/Pz8/Pz8/Pz8A////////////AAAAAAAAAAAAAAAAAAAAHx8fHx8fHx8fAAAAAAAAAAAAAAAAAAAAAAAAAAAAAAAAAAAAAAAAAAAAAAAAAAAAAAAAAACAwODw8Pj4+Pj8/Pz8/Pz8/Pz8/Pj4+Pjw8AAAAPD8/v///////x8PBwMBAQAAAAAAAAAAAQEBAQMDBwAAf///////////gAAAAAAAAAAAAPz8/Pz8/Pz8/Pz8/PwAAAcfP/////////z44ODAwICAgICAgIDA//////////8AAAAAAAABAQMHBw8PDx8fHx8fHx8fHx8fDw8PDwcHBwMAAAAAAAAAAAAAAAAAAAAAAAAAAAAAAAAAAAAAAAAAAAAA+Pj4+Pj4+Pj4AAAAAAAAAAAAAAAAAPj4+Pj4+Pj4AP///////////wAAAAAAAAAAAAAAAAD//////////wD///////////8/Pz8/Pz8/Pz8/Pz8///////////8A////////////AAAAAAAAAAAAAAAAAP//////////AB8fHx8fHx8fHwAAAAAAAAAAAAAAAAAfHx8fHx8fHwAAAAAAAAAAAAAAAAAAAAAAAAAAAAAAAAAAAAAAAAAA+Pj4+Pj4+Pj4////////////////////////////////////Hx8fHx8fHx8fAAAAAAAAAAAAAAAAAAAA+Pj4+Pj4+Pj4AAAAAAAA////////////AAAAAAAA////////////AAAAAAAA////////////AAAAgIDg//////////8fPz8/Pz8/Hx8fDw8HAwAA+Pj4+Pj4+Pj4AAAAAAAAAACAwODw+Pj4+Pj4eDgYCAAA////////////gMDg8Pj8/v///38/Hw8HAwEAAAAAAAAA//////////////////////PhwIAAAAAAAAAAAAAAAAAA////////////AAEDBw8fP3///////vz48ODAgAAAAAAAHx8fHx8fHx8fAAAAAAAAAAAAAQMHDx8fHx8fHx8eHBgQAAAAAAAAAAAAAAAAAAAAAAAAAAAAAAAAAAAAAAAAAAAA+Pj4+Pj4+Pj4AAAAAAAAAAAAAAAAAAAAAP///////////wAAAAAAAAAAAAAAAAAAAAD///////////8AAAAAAAAAAAAAAAAAAAAA////////////gICAgICAgICAgICAgICAAB8fHx8fHx8fHx8fHx8fHx8fHx8fHx8fHwAAAAAAAAAAAAAAAAAAAAAAAAAAAAAAAAAA+Pj4+Pj4+Pj4+PjwwAAAAAAAAAAAAAAAAMD4+Pj4+Pj4+Pj4+Pj//////////z9//////vjgAAAAAACA4Pz/////P///////////////////////AAABDz///////ODw/P////8/BwEA//////////////////////8AAAAAAAEHH39/f39/fx8DAAAAAAD///////////8fHx8fHx8fHwAAAAAAAAAAAAAAAAAAAAAAAAAAAB8fHx8fHx8fHwAAAAAAAAAAAAAAAAAAAAAAAAAAAAAAAAAAAAAAAAAAAAAAAAAA+Pj4+Pj4+Pj4+PDAAAAAAAAAAAAAAPj4+Pj4+Pj4AP//////////f//////88MAAAAAAAAD//////////wD//////////wAAAw8ff/////z44IAA//////////8A//////////8AAAAAAAABBx9//////v//////////AB8fHx8fHx8fAAAAAAAAAAAAAAEHHx8fHx8fHx8fHwAAAAAAAAAAAAAAAAAAAAAAAAAAAAAAAAAAAAAAAAAAAAAAAIDA4ODw8Pj4+Pz8/Pz8/Pz8/Pj4+Pjw4ODAgAAAAAAA8Pz/////////HwcDAQEAAAAAAAEBAwcP//////////zwAH///////////4AAAAAAAAAAAAAAAAAAAACA//////////9/AAcff/////////zw4MDAgICAgIDAwODw+P///////38fBwAAAAAAAAEDAwcHDw8PHx8fHx8fHx8fDw8PDwcDAwEAAAAAAAAAAAAAAAAAAAAAAAAAAAAAAAAAAAAAAAAAAAAAAAAAAAAA+Pj4+Pj4+Pj4+Pj4+Pj4+Pj4+PDw8ODgwIAAAP///////////wEBAQEBAQEDAw////////////j////////////4+Pj4+Pj4/Pz/////f38/Hw8B////////////AQEBAQEBAQEBAQAAAAAAAAAAAB8fHx8fHx8fHwAAAAAAAAAAAAAAAAAAAAAAAAAAAAAAAAAAAAAAAAAAAAAAAAAAAAAAAAAAAAAAAAAAAIDA4ODw8Pj4+Pz8/Pz8/Pz8/Pj4+Pjw8ODAgAAAAAAA8Pz/////////HwcDAQEAAAAAAAEBAwcP//////////zwAH///////////4AAAAAAAAAAAAAAAAAAAACA//////////9/AAcff/////////zw4MDAgICAgIDAwODw+P///////38fBwAAAAAAAAEDAwcHDw8PHx8fHx8fP////////+fDgwEAAAAAAAAAAAAAAAAAAAAAAAAAAAAAAAAAAAEDBw8PDw8PDgwIAAAA+Pj4+Pj4+Pj4+Pj4+Pj4+Pj4+PDw8ODAgAAAAAAAAP///////////wEBAQEBAQMDz///////////AAAAAAD////////////8/Pz8/Pz+/v/////Pz4cDAAAAAAAA////////////AAAAAAABAwcff////////vjggAAAAB8fHx8fHx8fHwAAAAAAAAAAAAABBx8fHx8fHx8eGAAAAAAAAAAAAAAAAAAAAAAAAAAAAAAAAAAAAAAAAAAAAIDA4PDw+Pj8/Pz8/Pz8/Pz8/Pj4+Pj48AAAfP/////////jwYGAAAAAAAAAAQEBAwMDAwAAAAMHDx8fPz9/f39/f//////+/v7+/Pz48OAAAPDg4MDAwMCAgICAgICAgMHB//////////8fAAcHDw8PDw8fHx8fHx8fHx8fDw8PDwcDAQAAAAAAAAAAAAAAAAAAAAAAAAAAAAAAAAAAAAAA+Pj4+Pj4+Pj4+Pj4+Pj4+Pj4+Pj4+Pj4+Pj4+Pj4+AABAQEBAQEBAQEBAf///////////wEBAQEBAQEBAQEBAAAAAAAAAAAAAAAA////////////AAAAAAAAAAAAAAAAAAAAAAAAAAAAAAD///////////8AAAAAAAAAAAAAAAAAAAAAAAAAAAAAAB8fHx8fHx8fHwAAAAAAAAAAAAAAAAAAAAAAAAAAAAAAAAAAAAAAAAAAAAAAAAAAAAAAAAAA+Pj4+Pj4+Pj4AAAAAAAAAAAAAAD4+Pj4+Pj4+PgA////////////AAAAAAAAAAAAAAD///////////8A////////////AAAAAAAAAAAAAAD///////////8ABz//////////8ODAgICAgIDAwOD/////////fw8AAAAAAQMHBw8PDx8fHx8fHx8fHw8PDw8HAwMAAAAAAAAAAAAAAAAAAAAAAAAAAAAAAAAAAAAAAAAAAAAACHj4+Pj4+Pj44IAAAAAAAAAAAAAAAAAAAMDw+Pj4+Pj4+BgAAAABD3/////////84AAAAAAAAAAAAIDw/v///////z8HAAAAAAAAAAABD3/////////4wAAAAIDw/P///////z8HAAAAAAAAAAAAAAAAAAADD3/////////4/P///////z8HAQAAAAAAAAAAAAAAAAAAAAAAAAADHx8fHx8fHx8fHx8PAQAAAAAAAAAAAAAAAAAAAAAAAAAAAAAAAAAAAAAAAAAAAAAAAAAAAAAAAAAAAAAACPj4+Pj4+Pj4gAAAAAAAAAAAAMD4+Pj4+Pj4+PiAAAAAAAAAAAAA4Pj4+Pj4+Pg4AAAAD//////////4gAAAAAAAgPz/////fw////////gAAAAAAADA/P///////38HAAAAAAAAH//////////4AACA+P////9/BwAAAA////////AAAMD8/////////wcAAAAAAAAAAAABH//////////4//////8PAAAAAAAAAR////////j/////////DwAAAAAAAAAAAAAAAAABHx8fHx8fHx8fHw8AAAAAAAAAAAAAAR8fHx8fHx8fHx8fAAAAAAAAAAAAAAAAAAAAAAAAAAAAAAAAAAAAAAAAAAAAAAAAAAAAAAAAAAAAAAAAAAAAAAAAAAAAAAAYOPj4+Pj4+PjgwAAAAAAAAAAAAIDg8Pj4+Pj4+HgYCAAAAAAAAAEHDz9///////748MDg+Pz//////z8fBwMAAAAAAAAAAAAAAAAAAACB4///////////////58EAAAAAAAAAAAAAAAAAAADA4Pj8//////8/HwcDBw8/f//////+/PDggAAAAAAAEBgeHx8fHx8fDwcBAAAAAAAAAAAAAAMHHx8fHx8fHxwYAAAAAAAAAAAAAAAAAAAAAAAAAAAAAAAAAAAAAAAAAAAAAAAAAAg4+Pj4+Pj4+PDggAAAAAAAAAAAAIDA8Pj4+Pj4+Pg4GAAAAAAAAQcPP3///////vzw4IDA8Pj+//////8/HwcDAAAAAAAAAAAAAAAAAAEDDx////////////8/DwcBAAAAAAAAAAAAAAAAAAAAAAAAAAAAAP///////////wAAAAAAAAAAAAAAAAAAAAAAAAAAAAAAAAAAHx8fHx8fHx8fAAAAAAAAAAAAAAAAAAAAAAAAAAAAAAAAAAAAAAAAAAAAAAAAAAAAAAAAAAAAAAAAAPj4+Pj4+Pj4+Pj4+Pj4+Pj4+Pj4+Pj4+Pj4+PgAAAEBAQEBAQEBAQEBAYHh8fn9//////9/Px8HAwEAAAAAAAAAgMDg8Pz+//////9/Hw8HAwAAAAAAAAAAgMDg+Pz+//////+/n4+DgYCAgICAgICAgICAgIAAHx8fHx8fHx8fHx8fHx8fHx8fHx8fHx8fHx8fHx8AAAAAAAAAAAAAAAAAAAAAAAAAAAAAAAAAAAAAAAAAAAAAAAAAAAAAAAAAAAAAAAAAAAAAAAAAAAAAAAAA8PDw8PDw8PDw8PDw8PDwBwcHBwcHBwcHBwcHBwcHAAAAAAAAAAAAAAAAAAAAAAAAAAAAAAAAAAAAAAAA"
_FONT_BLOB = binascii.a2b_base64(_FONT_B64)   # 1bitグリフの連結(MONO_VLSB形式)


def _glyph_fb(ch):
    info = _GLYPHS.get(ch)
    if info is None:
        return None, 0
    w, off = info
    n = w * (GLYPH_H // 8)
    fb = framebuf.FrameBuffer(bytearray(_FONT_BLOB[off:off + n]), w, GLYPH_H, framebuf.MONO_VLSB)
    return fb, w


def draw_label(s, gap=2):
    """埋め込みフォントで s を画面中央に描く。
    対応外の文字があれば、従来の拡大8x8にフォールバックする。"""
    total = 0
    for ch in s:
        info = _GLYPHS.get(ch)
        if info is None:
            draw_big_center(s, TEXT_SCALE, DISPLAY_BOLD)
            return
        total += info[0] + gap
    if s:
        total -= gap

    x = (OLED_W - total) // 2
    if x < 0:
        x = 0
    y = (OLED_H - GLYPH_H) // 2
    if y < 0:
        y = 0

    oled.fill(0)
    for ch in s:
        fb, w = _glyph_fb(ch)
        oled.blit(fb, x, y)
        x += w + gap
    oled_show()


# ============================================================
# 起動画面（スプラッシュ）
#   左：54x54のアイコン（0/1のバイナリ）  右：Train / Mascon の2行
# ============================================================

# アイコンの0/1データ。ここに 54行×54文字 を貼るとそれを表示します。
# 空のままなら、下の ICON_FILE（AE-RP2040内のファイル）を読みに行きます。
ICON_TEXT = """
000000000000000000000000000000000000000000000000000000
000000000000000000000000000000000000000000000000000000
000000000000000000000000000000000000000000000000000000
000000000000000000000000000000000000000000000000000000
000000000000000000000000011100000000000000000000000000
000000000011111111111111111111111111111111110000000000
000000000111111111111111111111111111111111111000000000
000000001111111111111111111111111111111111111100000000
000000011111111111111111111111111111111111111110000000
000000011111000000000000011110000000000000111110000000
000000011110000000000000011110000000000000011110000000
000000011110000000000000011110000000000000011110000000
000000011110000000000000011110000000000000011110000000
000000011110000000000000011110000000000000011110000000
000000011110000000000000011110000000000000011110000000
000000011110000000000000011110000000000000011110000000
000000011110000000000000011110000000000000011110000000
000000011110000000000000011110000000000000011110000000
000000011110000000000000011110000000000000011110000000
000000011110000000000000011110000000000000011110000000
000000011110000000000000011110000000000000011110000000
000000011110000000000000011110000000000000011110000000
000000011111000000000000111111000000000000111110000000
000000011111111111111111111111111111111111111110000000
000000011111111111111111111111111111111111111110000000
000000011111111111111111111111111111111111111110000000
000000011111111111111111111111111111111111111110000000
000000011110000000000000000000000000000000011110000000
000000011110000000000000000000000000000000011110000000
000000011110000000000000000000000000000000011110000000
000000011110000000000000000000000000000000011110000000
000000011110000000000000000000000000000000011110000000
000000011110000011110000000000000011110000011110000000
000000011110000011110000000000000011110000011110000000
000000011110000011110000000000000011110000011110000000
000000011110000001100000000000000001100000011110000000
000000011110000000000000000000000000000000011110000000
000000011110000000000000000000000000000000011110000000
000000011110000000000000000000000000000000011110000000
000000011111000000000000000000000000000000111110000000
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
"""
# （ICON_FILE / ICON_SIZE / ICON_PAD / BOOT_TEXT / BOOT_HOLD_S は先頭の設定にまとめました）


def _parse_icon(text):
    """0/1のテキストを、各行を文字列にしたリストへ変換する。"""
    rows = []
    for line in text.split("\n"):
        row = "".join(c for c in line if c in "01")
        if row:
            rows.append(row)
    return rows


def load_icon():
    """ICON_TEXT かファイルから 0/1 データを読み込む。無ければ None。"""
    if ICON_TEXT.strip():
        return _parse_icon(ICON_TEXT)
    try:
        with open(ICON_FILE) as f:
            return _parse_icon(f.read())
    except OSError:
        return None


def draw_icon(rows, x, y):
    """0/1データの '1' の位置に点を打つ。"""
    for r, row in enumerate(rows):
        for c, ch in enumerate(row):
            if ch == "1":
                oled.pixel(x + c, y + r, 1)


def draw_boot_screen():
    """起動画面を描く。左にアイコン、右に BOOT_TEXT。"""
    oled.fill(0)

    # アイコン：左に ICON_PAD の余白。縦は中央（54は64にほぼ一杯なので上下約5px）
    icon_x = ICON_PAD
    icon_y = (OLED_H - ICON_SIZE) // 2
    rows = load_icon()
    if rows:
        draw_icon(rows, icon_x, icon_y)
    else:
        # データ未配置のときは、配置が分かるように枠だけ描く
        oled.rect(icon_x, icon_y, ICON_SIZE, ICON_SIZE, 1)

    # テキスト：画像の右 ICON_PAD の位置から。縦は画面中央にそろえる
    text_x = icon_x + ICON_SIZE + ICON_PAD      # 10 + 54 + 10 = 74
    gap = 4
    block_h = len(BOOT_TEXT) * FONT_H + (len(BOOT_TEXT) - 1) * gap
    ty = (OLED_H - block_h) // 2
    for t in BOOT_TEXT:
        oled.text(t, text_x, ty, 1)
        ty += FONT_H + gap

    oled_show()


def _draw_center_text(s, y):
    """標準8pxフォントで、文字列sを水平中央に描く。"""
    x = (OLED_W - len(s) * FONT_W) // 2
    if x < 0:
        x = 0
    oled.text(s, x, y)


def draw_waiting(dots):
    """接続待ち画面。'Waiting for connection' の後に dots 個(0〜3)の '.' を表示。
    ドット数が変わっても位置がずれないよう、常に3文字幅で描く。"""
    oled.fill(0)
    line1 = "Waiting for"
    line2 = "connection" + "." * dots + " " * (3 - dots)
    _draw_center_text(line1, 22)
    _draw_center_text(line2, 34)
    oled_show()
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

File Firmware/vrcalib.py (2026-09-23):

# -*- coding: utf-8 -*-
"""
可変抵抗(VR)の電圧測定ツール  /  AE-RP2040 + MicroPython

マスコンのレバーを各ノッチに合わせながら、このスクリプトを実行して
表示される電圧を読み取ってください。その値をもとに、本体コード
(pot_keyboard.py) の LAYERS の電圧しきい値を決められます。

配線（本体コードと同じ）
  可変抵抗の中点 → ADC0 (GP26)、両端は 3V3 と GND

使い方
  このファイルを実行すると、電圧を繰り返し表示し続けます。
  レバーを各位置に止めて、そのときの電圧をメモしてください。
  止めるときは Ctrl-C（Thonnyなら停止ボタン）。
"""

from machine import ADC, Pin
import time

# ---- 設定（本体コードに合わせています）----
PIN_POT = 26          # ADC0
VREF = 3.3            # ADCの基準電圧[V]
SAMPLES = 16          # 平均化するサンプル数（多いほど安定、少ないほど反応が速い）
INTERVAL_MS = 200     # 表示の更新間隔[ms]

pot = ADC(PIN_POT)


def read_voltage():
    """可変抵抗の電圧[V]と、生の16bit値を返す。"""
    total = 0
    for _ in range(SAMPLES):
        total += pot.read_u16()
    raw = total // SAMPLES
    return raw / 65535.0 * VREF, raw


def main():
    print("VR電圧測定を開始します。レバーを各位置に止めて電圧を読んでください。")
    print("止めるには Ctrl-C（Thonnyなら停止ボタン）。")
    print("-" * 40)

    vmin = 99.0        # これまでに見た最小/最大（ノッチのブレ確認用）
    vmax = 0.0
    try:
        while True:
            v, raw = read_voltage()
            if v < vmin:
                vmin = v
            if v > vmax:
                vmax = v
            pct = v / VREF * 100
            # 例:  1.234 V  | raw 24512 | 37.4% | min 0.001 max 3.299
            print("{:5.3f} V | raw {:5d} | {:5.1f}% | min {:.3f} max {:.3f}"
                  .format(v, raw, pct, vmin, vmax))
            time.sleep_ms(INTERVAL_MS)
    except KeyboardInterrupt:
        print("-" * 40)
        print("終了しました。")


if __name__ == "__main__":
    main()
